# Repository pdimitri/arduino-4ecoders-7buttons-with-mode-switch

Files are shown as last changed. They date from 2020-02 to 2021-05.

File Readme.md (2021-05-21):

# Four Encoders, three push buttons in three modes joystick

This Arduino Sketch is meant to be used with an Arduino Pro Micro or any other Arduino with an ATmega32U4 chipset, that may act as an USB Joystick Device.

**All in all my prototype emulates up to 12 encoders and additional 21 buttons.**

The sketch uses the following libraries, that must be installed from "tools" menu within the Arduino IDE:

* Joystick library from  Matthew Heironimus, https://github.com/MHeironimus/ArduinoJoystickLibrary
* Bounce2 library from Thomas Fredericks, https://github.com/thomasfredericks/Bounce2
* Keypad Library from Mark Stanley and Alexander Brevig, https://www.arduinolibraries.info/libraries/keypad

The sketch also uses the Encoder code from Ben Buxton 
More info: http://www.buxtronix.net/2011/10/rotary-encoders-done-properly.html

The base idea for this sketch is from TOPMO 3 
https://www.xsimulator.net/community/threads/diy-arduino-buttonbox.8302/

To identify the pin numbers, that are used in the sketch, on your Arduino refer to this pin layout https://learn.sparkfun.com/tutorials/pro-micro--fio-v3-hookup-guide/hardware-overview-pro-micro

## Project Goal
I wanted to build a simple - but versatile - input device for computer games (especially flight simulators) that supports some endless rotary encoders with push buttons, and that doesn't need any special software plugins on the PC side to make it work in any type of game you like, that supports custom joystick configuration. 

Given you have an Arduino Pro Micro with already soldered pin headers, the hardware should be easy to assemble, mostly without the need to solder anything. With the exception of the status LED everything else is connectible via jumper wires and insulating screw joints.

**Total build time, using the same connections as in my Arduino sketch, will take approximately 1 hour.**

I wanted to get a maximum number of joystick commands from a single Arduino, without the need to use more complex electronic devices like multiplexer boards, busses etc. Therefore I use a single status LED to indicate one of three modes instead of occupying two more digital outputs of the Arduino with two more LEDs, so that every mode would be indicated by a single LED. 

## Description of Hardware

My prototype consists of these parts:

* An Arduino Pro Micro with soldered pin headers 
* A couple of jumper wires like these (female/female and female/male) https://www.amazon.de/Female-Female-Male-Female-Male-Male-Steckbr%C3%BCcken-Drahtbr%C3%BCcken-bunt/dp/B01EV70C78
* Four momentary push button like these: 
https://www.amazon.de/gp/product/B076SYC21Q
* Four cheap encoders with push buttons 
https://www.amazon.de/gp/product/B07D356LRH

One of the push buttons acts as a mode switch, that allows to use every encoder and button in three different modes. That means, that i.e. a single enoder may emulate up to 9 different joystick buttons.

A status LED (connected to a digital output pin via a 220 Ohm resistor) shows the currently selected mode. The mode button cycles through all three modes.

* LED off: Mode 1
* LED on: Mode 2
* LED blinking: Mode 3

## This is how my prototype looks like

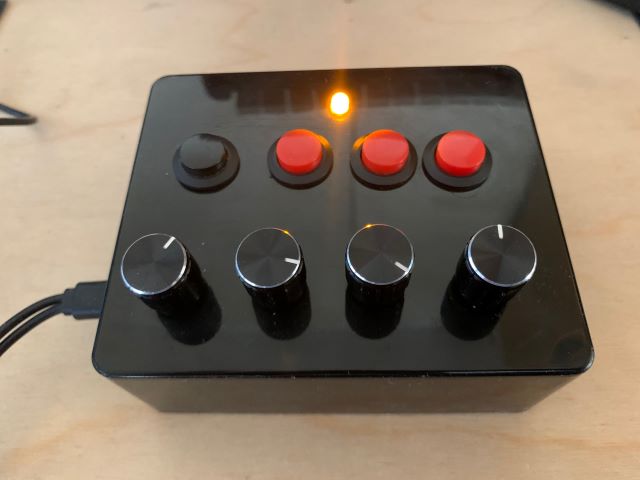
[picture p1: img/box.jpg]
Image of Prototype


## Wiring

Most of the wiring is done by simply using the jumper wires to plug everything together. You may also get momentary push buttons on Amazon with wires already soldered to them. So with the exception of the LED with its Resistor everything is Plug & Play.

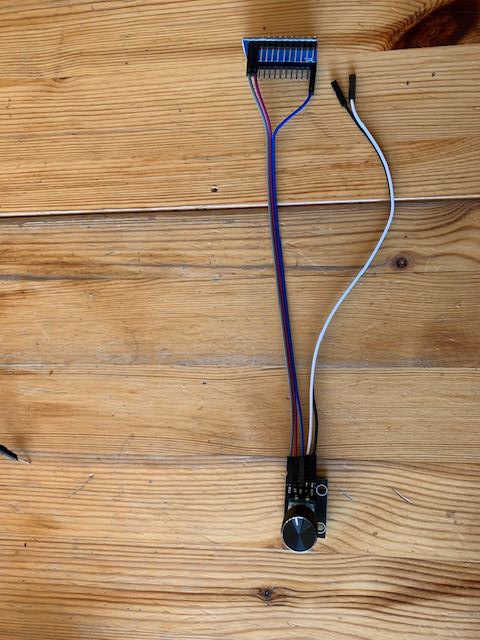
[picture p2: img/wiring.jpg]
Wiring 1


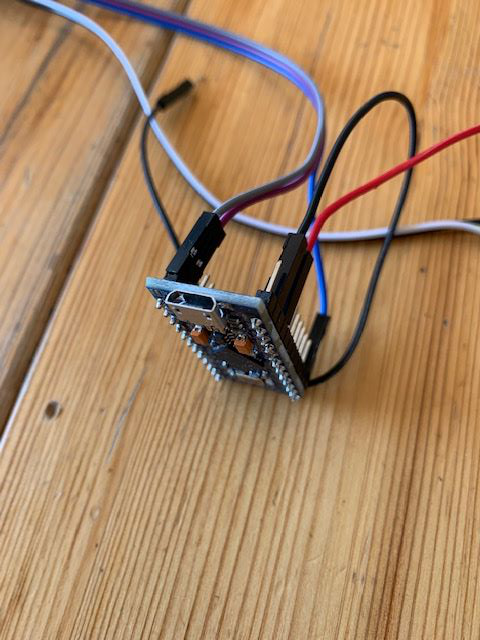
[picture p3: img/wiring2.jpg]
Wiring 2


## Fritzing Sketches

This is a simplified wiring diagram. You need to connect all black connections to a common ground (GND)pin on the Arduino, and all red connections to a common 5 Volt source (Vcc) on the Arduino-

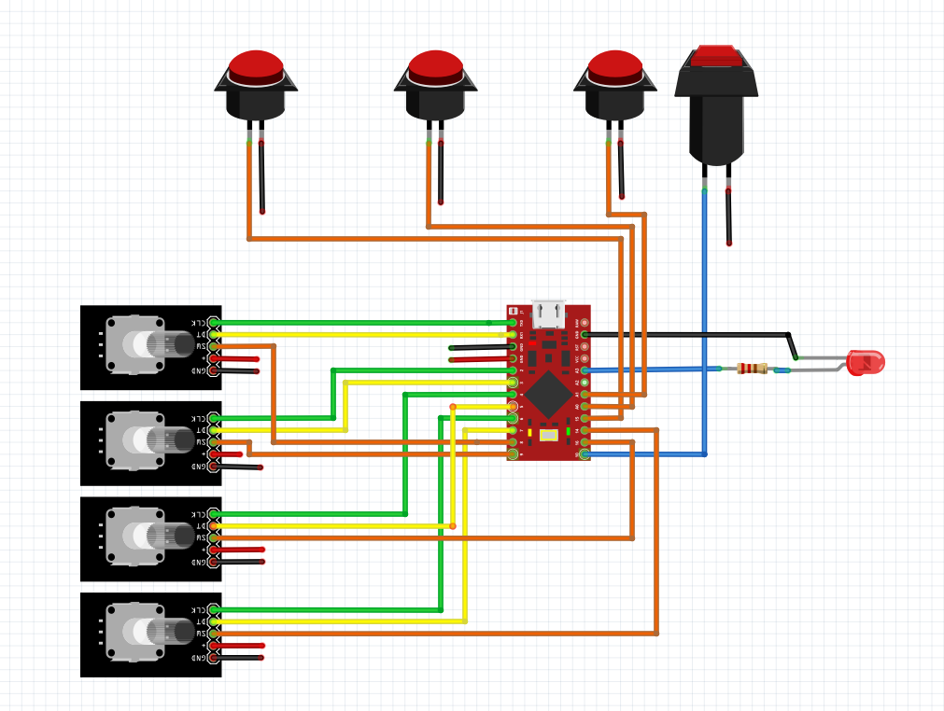
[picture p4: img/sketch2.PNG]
Simplified Sketch


The next Sketch shows the complete wiring, including ground and power connectors. I connected ground and power connections with a Stripboard and some soldering, but using insulating screw joints instead will work as well.

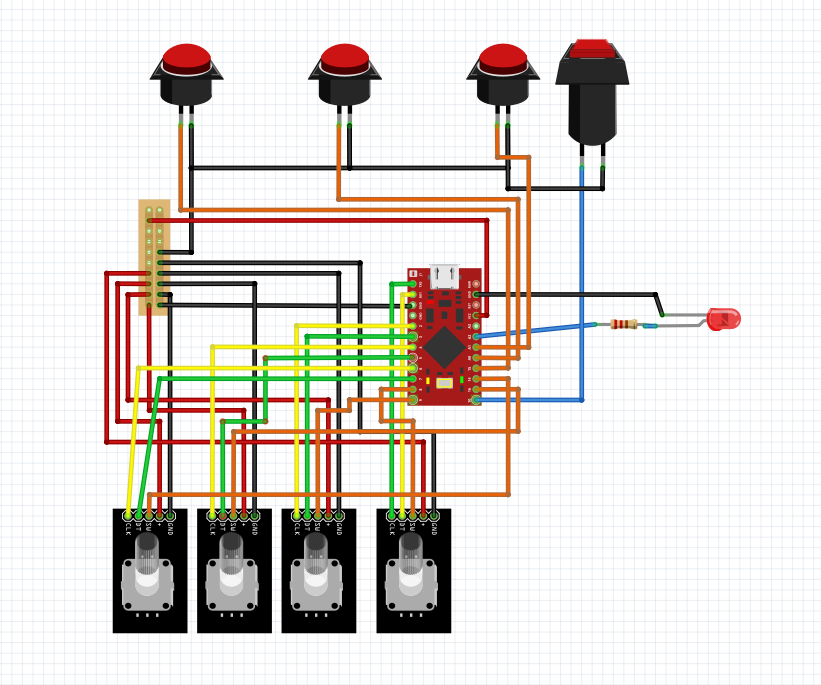
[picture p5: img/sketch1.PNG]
Real Sketch


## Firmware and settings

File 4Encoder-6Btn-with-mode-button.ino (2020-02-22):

//Buttonbox with Encoders sketch
//Supports up to 21 buttons and up to 4 encoders
//based on the Sketch from TOPMO3
//
//
//Arduino IDE 1.6.6 (or above) !
//
//Should be used with an Arduino Pro Micro or any other micro controller with an ATmega32U4 chipset, that may act as an USB Device
//
//To identify the pin mumbers on your Arduino refer to this pin layout https://learn.sparkfun.com/tutorials/pro-micro--fio-v3-hookup-guide/hardware-overview-pro-micro
//
//Joystick library from  Matthew Heironimus, https://github.com/MHeironimus/ArduinoJoystickLibrary
// 
//Encoders code from Ben Buxton
//More info: http://www.buxtronix.net/2011/10/rotary-encoders-done-properly.html
// 
//Thank you guys! :)
//



//Uncomment this for HALFSTEP encoder operation
//#define HALF_STEP

#include <Keypad.h>
#include <Joystick.h>
#include <Bounce2.h>

#define ENABLE_PULLUPS
#define NUMROTARIES 4
#define NUM_JOYSTICK_BUTTONS 32


const int NUM_MODES = 3;
const int NUM_ENCODER_BUTTONS = 2;
const int NUM_SWITCHES = 8;

struct rotariesdef {
  byte pin1;
  byte pin2;
  int buttons [NUM_MODES][NUM_ENCODER_BUTTONS];
  volatile unsigned char state;
};

struct switchdef {
  byte pin;
  byte joystick_button[NUM_MODES];
};

struct hatdef {
  byte hat_nr;
  int angle;
};

byte MODE = 0;
byte LAST_MODE = 0;
unsigned long previousMillis = 0;
int ledState = LOW;

//=====================================================================
//Please adjust to your personal choice of PIN Connections from here...
//=====================================================================

//Select the digital input pin numbers where you attached the mode switch (push button) and the LED (use a 22O Ohm resistor in Front of LED)
const int MODE_PIN = 10;
byte LED_PIN = 21; 


//The first two numbers in each line are the digital inputs where you attached the CLK and DT connectors of the encoders 
rotariesdef rotaries[NUMROTARIES] {
  {0,1,{{1,2},{3,4},{5,6}},0},
  {2,3,{{7,8},{9,10},{11,12}},0},
  {4,5,{{13,14},{15,16},{17,18}},0},
  {6,7,{{19,20},{21,22},{23,24}},0},
};

//The first number in each line are the pins with simple push buttons attached
switchdef switches[NUM_SWITCHES] = {
  {8,{25,26,27}},
  {9,{28,29,30}},
  {14,{31,32,33}},
  {15,{34,35,36}},
  {16,{37,38,39}},
  {18,{40,41,42}},
  {19,{43,44,45}},
  {20,{47,48,49}},
};

//=====================================================================
//...to here
//=====================================================================

hatdef hatswitches[16] = {
  {0,0},
  {0,45},
  {0,90},
  {0,135},
  {0,180},
  {0,225},
  {0,270},
  {0,315},
  {1,0},
  {1,45},
  {1,90},
  {1,135},
  {1,180},
  {1,225},
  {1,270},
  {1,315}
};

// Last state of the button
int lastButtonState[NUM_SWITCHES] = {0,0,0,0,0,0,0,0};

bool hatValueChanged[2] = {false, false};
int lastHatPin = 0;
int lastHatState[2] = {0,0};
bool valueChanged[2] = {false, false};



//initialize an Joystick with 34 buttons;
Joystick_ Joystick(JOYSTICK_DEFAULT_REPORT_ID, 
  JOYSTICK_TYPE_JOYSTICK, 32, JOYSTICK_DEFAULT_HATSWITCH_COUNT,
  false, false, false, false, false, false,
  false, false, false, false, false);

Bounce  myButton  = Bounce();

unsigned int interval = 1000;

void blinker(){
  unsigned long currentMillis = millis();

  if (currentMillis - previousMillis >= interval) {
    // save the last time you blinked the LED
    previousMillis = currentMillis;

    // if the LED is off turn it on and vice-versa:
    if (ledState == LOW) {
      ledState = HIGH;
    } else {
      ledState = LOW;
    }

    // set the LED with the ledState of the variable:
    digitalWrite(LED_PIN, ledState);
  }
}


void CheckAllButtons(void) {
      byte hatArrayIndex;

      
      for (int index = 0; index < NUM_SWITCHES; index++)
      {
        int currentButtonState = !digitalRead(switches[index].pin);

        if (currentButtonState != lastButtonState[index])
        {
            //switches[index].joystick_button[LAST_MODE] is the number of the joystick button that should be emulated.
            //because a maximum of 32 Buttons is supported by the joystick library, we also emulate two 
            //hat switches, which gives us up to 16 additional "buttons"
            //remember: with the push buttons of the encoders, all in all we already use up to 32 emulated "buttons" for the four encoders in their three different modes
            
            if(switches[index].joystick_button[LAST_MODE] < 32){
              Joystick.setButton(switches[index].joystick_button[LAST_MODE], currentButtonState);
            } else{
              hatArrayIndex = switches[index].joystick_button[LAST_MODE] - 32;
              if(currentButtonState==LOW){
                    Joystick.setHatSwitch(hatswitches[hatArrayIndex].hat_nr, -1);
              } else {
                Joystick.setHatSwitch(hatswitches[hatArrayIndex].hat_nr, hatswitches[hatArrayIndex].angle);
              }
            }
            lastButtonState[index] = currentButtonState;
        }
      }
}



void CheckMODE_PIN(){
  myButton.update();
  if (myButton.risingEdge()) {
    if (LAST_MODE < (NUM_MODES - 1)){
      LAST_MODE++;
    } else {
      LAST_MODE=0;
    }
    
    switch (LAST_MODE) {
    case 0:    // your hand is on the sensor
      digitalWrite(LED_PIN, LOW);
      break;
    case 1:    // your hand is close to the sensor
      digitalWrite(LED_PIN, HIGH);
      break;
    }
    
  }
}


#define DIR_CCW 0x10
#define DIR_CW 0x20
#define R_START 0x0

#ifdef HALF_STEP
// Use the half-step state table (emits a code at 00 and 11)
#define R_CCW_BEGIN 0x1
#define R_CW_BEGIN 0x2
#define R_START_M 0x3
#define R_CW_BEGIN_M 0x4
#define R_CCW_BEGIN_M 0x5
const unsigned char ttable[6][4] = {
  // R_START (00)
  {R_START_M,            R_CW_BEGIN,     R_CCW_BEGIN,  R_START},
  // R_CCW_BEGIN
  {R_START_M | DIR_CCW, R_START,        R_CCW_BEGIN,  R_START},
  // R_CW_BEGIN
  {R_START_M | DIR_CW,  R_CW_BEGIN,     R_START,      R_START},
  // R_START_M (11)
  {R_START_M,            R_CCW_BEGIN_M,  R_CW_BEGIN_M, R_START},
  // R_CW_BEGIN_M
  {R_START_M,            R_START_M,      R_CW_BEGIN_M, R_START | DIR_CW},
  // R_CCW_BEGIN_M
  {R_START_M,            R_CCW_BEGIN_M,  R_START_M,    R_START | DIR_CCW},
};
#else
// Use the full-step state table (emits a code at 00 only)
#define R_CW_FINAL 0x1
#define R_CW_BEGIN 0x2
#define R_CW_NEXT 0x3
#define R_CCW_BEGIN 0x4
#define R_CCW_FINAL 0x5
#define R_CCW_NEXT 0x6

const unsigned char ttable[7][4] = {
  // R_START
  {R_START,    R_CW_BEGIN,  R_CCW_BEGIN, R_START},
  // R_CW_FINAL
  {R_CW_NEXT,  R_START,     R_CW_FINAL,  R_START | DIR_CW},
  // R_CW_BEGIN
  {R_CW_NEXT,  R_CW_BEGIN,  R_START,     R_START},
  // R_CW_NEXT
  {R_CW_NEXT,  R_CW_BEGIN,  R_CW_FINAL,  R_START},
  // R_CCW_BEGIN
  {R_CCW_NEXT, R_START,     R_CCW_BEGIN, R_START},
  // R_CCW_FINAL
  {R_CCW_NEXT, R_CCW_FINAL, R_START,     R_START | DIR_CCW},
  // R_CCW_NEXT
  {R_CCW_NEXT, R_CCW_FINAL, R_CCW_BEGIN, R_START},
};
#endif


/* Read input pins and process for events. Call this either from a
 * loop or an interrupt (eg pin change or timer).
 *
 * Returns 0 on no event, otherwise 0x80 or 0x40 depending on the direction.
 */
unsigned char rotary_process(int _i) {
   unsigned char pinstate = (digitalRead(rotaries[_i].pin2) << 1) | digitalRead(rotaries[_i].pin1);
  rotaries[_i].state = ttable[rotaries[_i].state & 0xf][pinstate];
  return (rotaries[_i].state & 0x30);
}

void CheckAllEncoders(void) {
  for (int i=0;i<NUMROTARIES;i++) {
    unsigned char result = rotary_process(i);
    if (result == DIR_CCW) {
        Joystick.setButton(rotaries[i].buttons[LAST_MODE][0]-1, 1); delay(50); Joystick.setButton(rotaries[i].buttons[LAST_MODE][0]-1, 0);
    }
    
    if (result == DIR_CW) {
        Joystick.setButton(rotaries[i].buttons[LAST_MODE][1]-1, 1); delay(50); Joystick.setButton(rotaries[i].buttons[LAST_MODE][1]-1, 0);
      }
    };
}



/* Call this once in setup(). */
void rotary_init() {
  for (int i=0;i<NUMROTARIES;i++) {
    pinMode(rotaries[i].pin1, INPUT);
    pinMode(rotaries[i].pin2, INPUT);
    #ifdef ENABLE_PULLUPS
      digitalWrite(rotaries[i].pin1, HIGH);
      digitalWrite(rotaries[i].pin2, HIGH);
    #endif
  }
}

void buttons_init() {
    for (int index = 0; index < NUM_SWITCHES; index++) {
      pinMode(switches[index].pin,INPUT_PULLUP);
    }
}




void setup() {
  Serial.begin(9600);
  
  pinMode(MODE_PIN,INPUT_PULLUP);
  pinMode(LED_PIN, OUTPUT);
  
  myButton.attach(MODE_PIN);
  myButton.interval(5); // 5ms zum Entprellen
  
  buttons_init();
  Joystick.begin();

}



void loop() { 
  
  CheckMODE_PIN();
  CheckAllEncoders();
  CheckAllButtons();

  if(LAST_MODE == 2){
    blinker();
  }
}

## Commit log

2020-02-22 Fritzing and Images
    [Fritzing_Sketch.fzz, Fritzing_Sketch2.fzz]
2020-02-22 changed amazon link to encoders
